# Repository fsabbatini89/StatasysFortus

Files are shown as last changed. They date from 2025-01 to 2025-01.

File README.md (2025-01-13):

# StatasysFortus
This is a man-in-the-middle technique for Statasys Fortus machine

Basically you put a real cartdrige on each bay with full filament on it.
The PCB of the bay is connected to this project board input and output is connected to the original
fortus cable.
This PCB captures the "WRITE ON CARTDRIGE" commands from the main cpu to the bay pcb and replies accordingly
but that message never gets to the bay pcb so the chip is never ever written so after a machine reset, cartdrige is
full again.

Cartridge cache file of machine as to be erased so the serial number of cartrige is forggoten at startup so machine thinks
new full filament is set.

Happy printing!

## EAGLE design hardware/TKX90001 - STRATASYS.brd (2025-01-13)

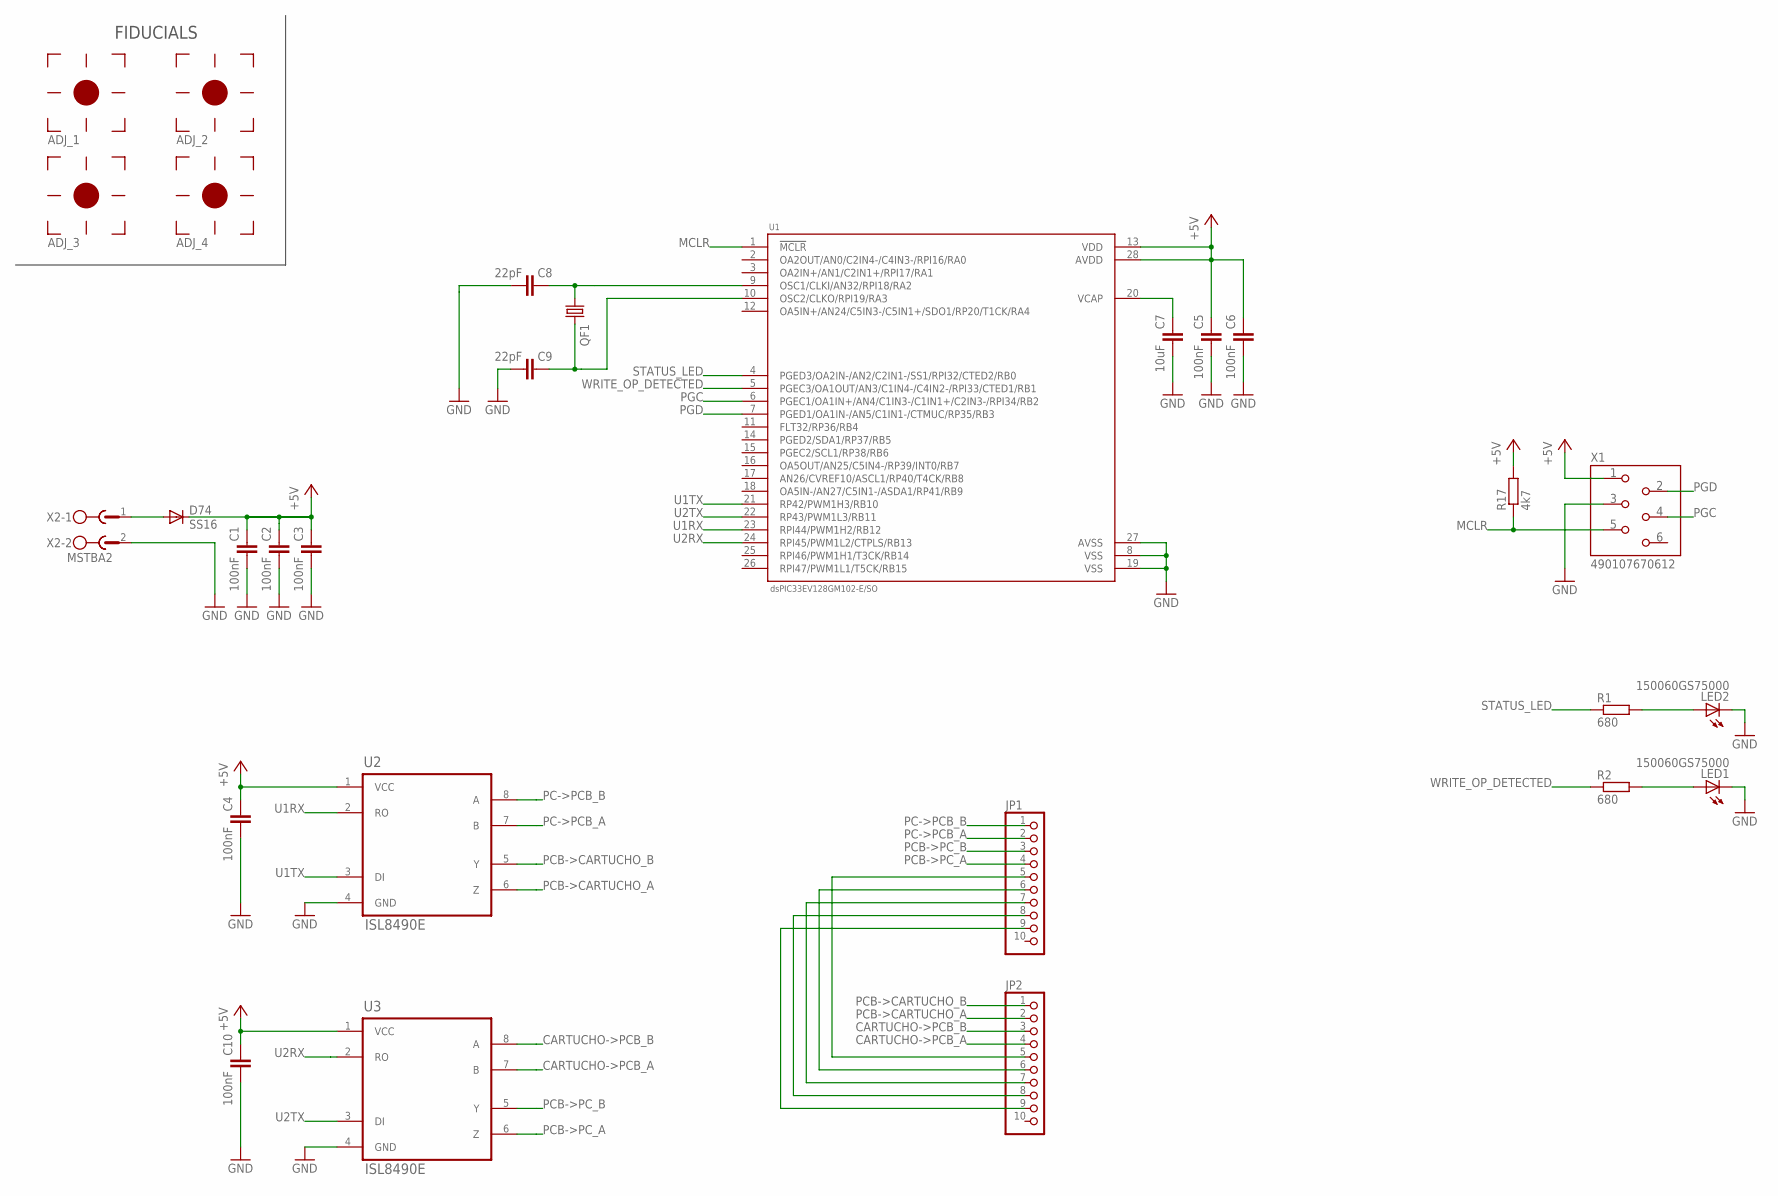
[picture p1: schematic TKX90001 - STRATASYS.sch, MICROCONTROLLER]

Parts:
ADJ_1, ADJ_2, ADJ_3, ADJ_4: FIDUCIAL
C1, C2, C3, C4, C5, C6, C10: 100nF; C0603K; PARTNO 885012206020
C7: 10uF; C1206K; PARTNO TAJA106K016RNJV
C8, C9: 22pF; C0603K; PARTNO C0603C220M4RACAUTO
D74: SS16; SMB; PARTNO SS16T3G
JP1, JP2: PINHD-1X10/90; 1X10/90
LED1, LED2: 150060GS75000; SML0603; PARTNO 150060GS75000
QF1: CRYSTALHC49S; HC49/S
R1, R2: 680; R0603; PARTNO RC0603FR-13680RL
R17: 4k7; R0603; PARTNO RC0603FR-074K7L
U1: dsPIC33EV128GM102-E/SO; SOIC127P1028X256-28N; PARTNO dsPIC33EV128GM102-E/SO
U2, U3: ISL8490E; SOIC127P600X175-8N; PARTNO ISL8490EIBZ
X1: 490107670612; REDFIT_6POS
X2: MSTBA2

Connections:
+5V: C1.1, C2.1, C3.1, C4.1, C5.1, C6.1, C10.1, D74.C, R17.2, U1.13 (VDD), U1.28 (AVDD), U2.1 (VCC), U3.1 (VCC), X1.P$1
CARTUCHO->PCB_A: JP2.4, U3.7 (B)
CARTUCHO->PCB_B: JP2.3, U3.8 (A)
GND: C1.2, C2.2, C3.2, C4.2, C5.2, C6.2, C7.2, C8.2, C9.2, C10.2, LED1.C, LED2.C, U1.8 (VSS), U1.19 (VSS), U1.27 (AVSS), U2.4 (GND), U3.4 (GND), X1.P$3, X2.2
MCLR: R17.1, U1.1 (!MCLR), X1.P$5
unnamed: LED1.A, R2.2
unnamed: D74.A, X2.1
unnamed: C7.1, U1.20 (VCAP)
unnamed: C8.1, QF1.1, U1.9 (OSC1/CLKI/AN32/RPI18/RA2)
unnamed: LED2.A, R1.2
unnamed: C9.1, QF1.2, U1.10 (OSC2/CLKO/RPI19/RA3)
unnamed: JP1.5, JP2.5
unnamed: JP1.6, JP2.6
unnamed: JP1.7, JP2.7
unnamed: JP1.8, JP2.8
unnamed: JP1.9, JP2.9
PC->PCB_A: JP1.2, U2.7 (B)
PC->PCB_B: JP1.1, U2.8 (A)
PCB->CARTUCHO_A: JP2.2, U2.6 (Z)
PCB->CARTUCHO_B: JP2.1, U2.5 (Y)
PCB->PC_A: JP1.4, U3.6 (Z)
PCB->PC_B: JP1.3, U3.5 (Y)
PGC: U1.6 (PGEC1/OA1IN+/AN4/C1IN3-/C1IN1+/C2IN3-/R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), X1.P$4
PGD: U1.7 (PGED1/OA1IN-/AN5/C1IN1-/CTMUC/RP35/RB3), X1.P$2
STATUS_LED: R1.1, U1.4 (PGED3/OA2IN-/AN2/C2IN1-/SS1/RPI32/CTED2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)
U1RX: U1.23 (RPI44/PWM1H2/RB12), U2.2 (RO)
U1TX: U1.21 (RP42/PWM1H3/RB10), U2.3 (DI)
U2RX: U1.24 (RPI45/PWM1L2/CTPLS/RB13), U3.2 (RO)
U2TX: U1.22 (RP43/PWM1L3/RB11), U3.3 (DI)
WRITE_OP_DETECTED: R2.1, U1.5 (PGEC3/OA1OUT/AN3/C1IN4-/C4IN2-/RPI33/CT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)

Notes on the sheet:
FIDUCIALS

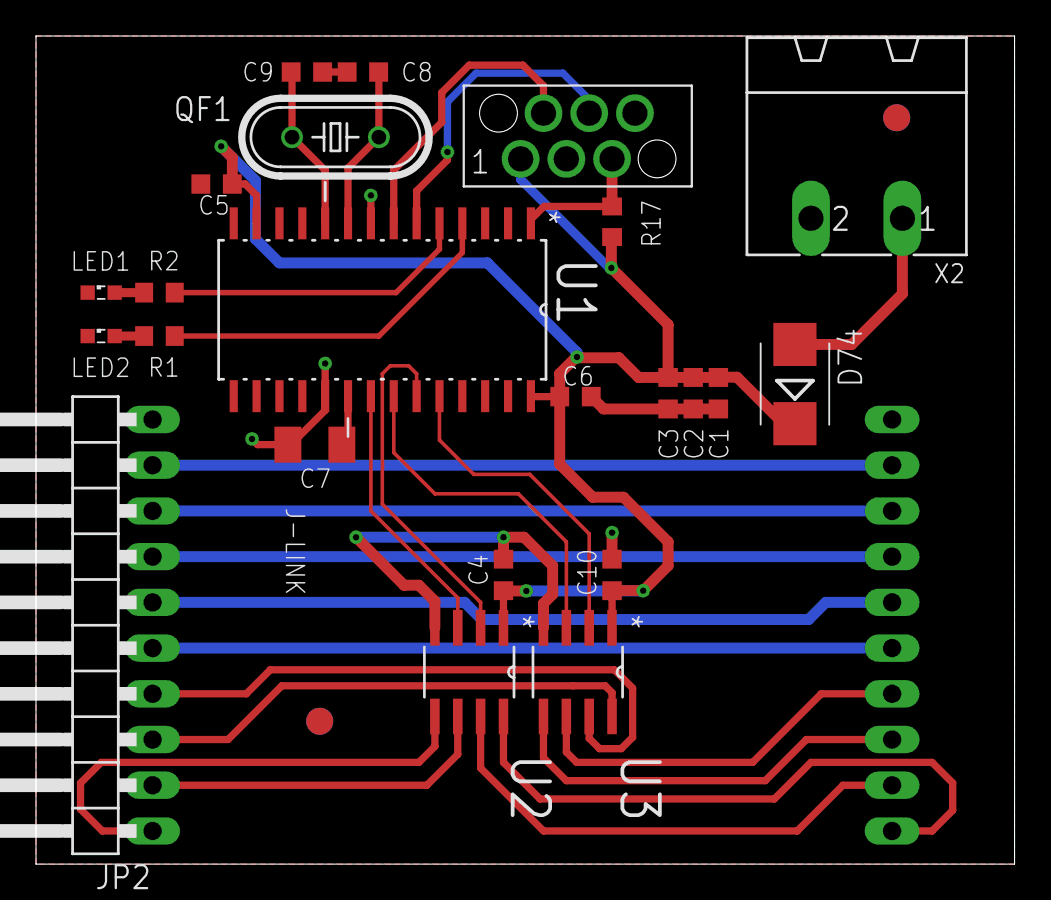
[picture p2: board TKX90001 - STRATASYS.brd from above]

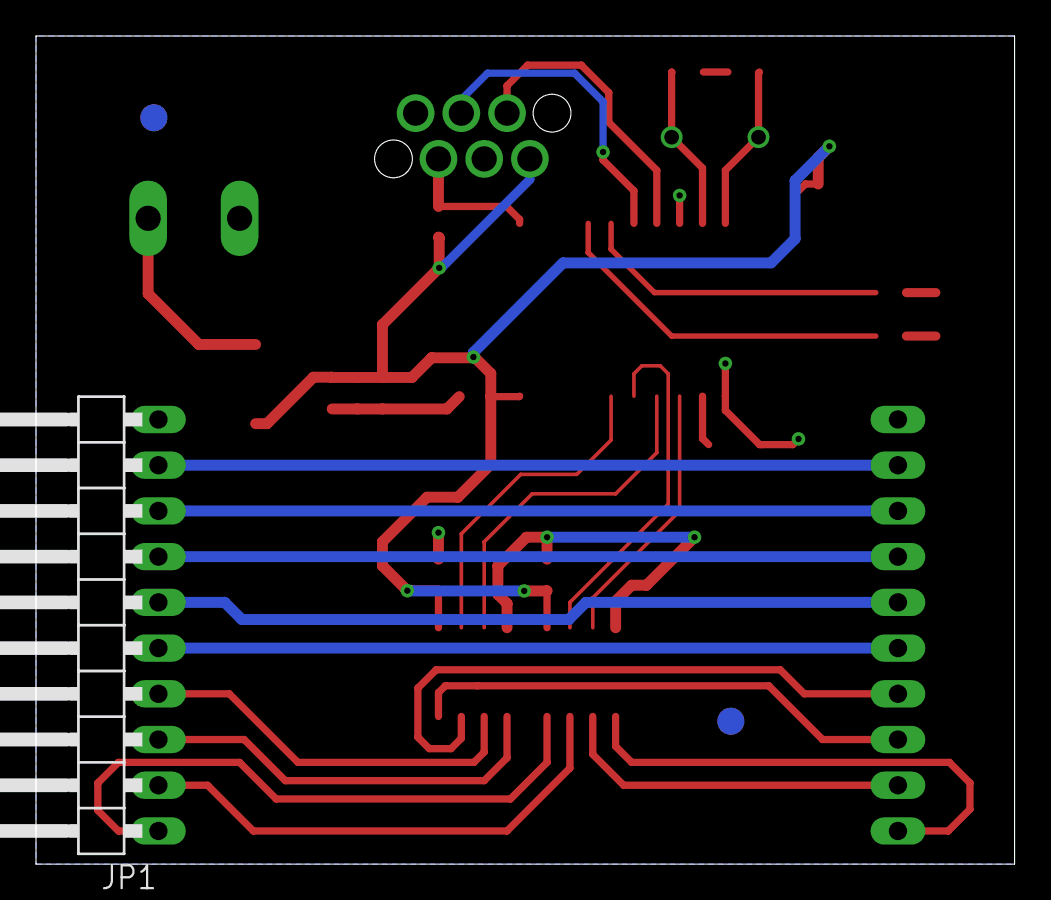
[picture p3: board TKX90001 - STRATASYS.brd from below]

Board: 2 copper layers, 54.4 x 46.0 mm, 28 parts (3 on the bottom side), 30 nets.

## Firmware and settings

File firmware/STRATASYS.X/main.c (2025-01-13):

/******************************************************************************/
/* Files to Include                                                           */
/******************************************************************************/

/* Device header file */
#if defined(__XC16__)
    #include <xc.h>
#elif defined(__C30__)
    #if defined(__dsPIC30F__)
        #include <p30Fxxxx.h>
    #endif
#endif

#include <stdint.h>        /* Includes uint16_t definition                    */
#include <stdbool.h>       /* Includes true/false definition                  */

#include "system.h"        /* System funct/params, like osc/peripheral config */
#include "user.h"          /* User funct/params, such as InitApp              */
#include "stratasys/pkt.h"

#include <uart.h>

/******************************************************************************/
/* Global Variable Declaration                                                */
/******************************************************************************/
RSTATE host; 
RSTATE cartdrige; 
RSTATE *r1 = &host;
RSTATE *r2 = &cartdrige;

/* HOST TO CARTDRIGE */
uint8_t pbuf[PKT_MAX_PLEN];
uint8_t dbuf[PKT_MAX_DLEN];

/* CARTRIDGE TO HOST */
uint8_t pbuf2[PKT_MAX_PLEN];
uint8_t dbuf2[PKT_MAX_DLEN];

uint8_t pkt_buf[PKT_MAX_PLEN];
uint8_t pkt_ibuf[PKT_MAX_PLEN];
uint8_t pkt_send_buf[PKT_MAX_PLEN + PKT_N_LEADIN];

uint8_t pkt_buf2[PKT_MAX_PLEN];
uint8_t pkt_ibuf2[PKT_MAX_PLEN];
uint8_t pkt_send_buf2[PKT_MAX_PLEN + PKT_N_LEADIN];

uint8_t cmdWriteData[PKT_MAX_DLEN];
uint16_t cmdWriteDataLength;

uint8_t ABS_M30_FULL[130] = {0x00 ,0x80 ,0x02 ,0x7f ,0x12 ,0xca ,0x6b ,0x41 ,0xe3 ,0xcd ,0x50 ,0xe9 ,0x80 ,0x84 ,0x37 ,0x53 ,0x22 ,0x8e ,0xe1 ,0x35 ,0x05 ,0x6f ,0x27 ,0xad ,0x58 ,0xf2 ,0x07 ,0x5f ,0xf3 ,0x9d ,0xbf ,0xdd ,0xf2 ,0x7f ,0x3c ,0x32 ,0xa1 ,0x6b ,0x55 ,0xbe ,0xed ,0x93 ,0x6d ,0x7d ,0x05 ,0x32 ,0xa5 ,0x79 ,0xe4 ,0xd8 ,0xa8 ,0x6d ,0x99 ,0xcb ,0xd1 ,0x09 ,0x97 ,0xe6 ,0xee ,0x4f ,0xac ,0xdc ,0xf3 ,0xdf ,0xcc ,0x84 ,0x41 ,0xe2 ,0x78 ,0x30 ,0x32 ,0x5a ,0xe9 ,0x89 ,0x61 ,0x75 ,0xe6 ,0xdc ,0x76 ,0xb6 ,0x89 ,0xf6 ,0xba ,0xc0 ,0x31 ,0xf3 ,0x18 ,0xd6 ,0x87 ,0x35 ,0x3b ,0x98 ,0x9a ,0xc8 ,0x38 ,0x25 ,0x60 ,0x44 ,0x54 ,0x0d ,0x3a ,0x2d ,0xd8 ,0x4d ,0x13 ,0x16 ,0x53 ,0x54 ,0x52 ,0x41 ,0x54 ,0x41 ,0x53 ,0x59 ,0x53 ,0x9b ,0xaa ,0xff ,0xf0 ,0x82 ,0x3f ,0xa0 ,0x38 ,0x11 ,0xad ,0x82 ,0x86 ,0xfd ,0xf9 ,0x89};

uint8_t lastCommandNumber;

bool waitForHost = true;

/******************************************************************************/
/* Main Program                                                               */
/******************************************************************************/

enum {
    WRITE_CATRIDGE_WRITE,               /* HOST -> CARTDRIGE */
    WRITE_CATRIDGE_ACK_WRITE,           /* CARTDRIGE -> HOST */
    WRITE_CATRIDGE_WRITE_DONE,          /* CARTDRIGE -> HOST */
    WRITE_CATRIDGE_WAIT_FOR_HOST_ASK,
    WRITE_CATRIDGE_ACK_WRITE_DONE,      /* HOST -> CARTDRIGE */
    WRITE_CATRIDGE_WAIT_FOR_HOST_READ,
    WRITE_CATRIDGE_READ_START          /* HOST -> CARTDRIGE */
};

uint8_t stateWrite;

volatile unsigned int pepe;

int16_t main(void)
{
    uint8_t *pdata1, pdata1_len;
    uint8_t *pdata2, pdata2_len;

    /* Configure the oscillator for the device */
    ConfigureOscillator();

    /* Initialize IO ports and peripherals */
    InitApp();

    stateWrite = WRITE_CATRIDGE_WRITE;
    
//    pbuf[0] = 'f';
//    pbuf[1] = 'r';
//    pbuf[2] = 'a';
//    pbuf[3] = 'n';
//    pbuf[4] = 'c';
//    pbuf[5] = 'o';
//
//    LATBbits.LATB1 = 0;
//    LATBbits.LATB1 = 1;
//            
//    while(1){
//        pkt_send2(r2, 1, 2, 3, PKTF_RESP_WRITE_CARTDRIGE, 6, pbuf);
//        LATBbits.LATB0 ^= 1;
//        LATBbits.LATB1 ^= 1;
//        delay_ms(1000);
//    }
    
    while(1)
    {
        switch(stateWrite){
            case WRITE_CATRIDGE_ACK_WRITE:
                /* To this command we need to answer with PKTF_RESP_WRITE_CARTDRIGE and 0 data */                
                pdata2 = NULL;
                pdata2_len = 0;
                pkt_send(r2, PKT_SRC(pbuf), PKT_DST(pbuf), PKT_NUMCMD(pbuf), PKTF_RESP_WRITE_CARTDRIGE, pdata2_len, pdata2);
                
                stateWrite = WRITE_CATRIDGE_WRITE_DONE;
            break;
                           
            case WRITE_CATRIDGE_WRITE_DONE:
                /* To this command we need to answer with PKTF_RESP_WRITTEN_CARTDRIGE and 0 data */                
                pdata2 = NULL;
                pdata2_len = 0;
                    
                lastCommandNumber++;
                    
                pkt_send(r2, PKT_SRC(pbuf), PKT_DST(pbuf), lastCommandNumber, PKTF_RESP_WRITTEN_CARTDRIGE, pdata2_len, pdata2);
                
                stateWrite = WRITE_CATRIDGE_WAIT_FOR_HOST_ASK;
                
            break;
                
            case WRITE_CATRIDGE_ACK_WRITE_DONE:    
                /* To this command we need to answer with PKTF_RESP_WRITE_CARTDRIGE and 0 data */                
                pdata2 = NULL;
                pdata2_len = 0;

                pkt_send(r2, PKT_SRC(pbuf), PKT_DST(pbuf), PKT_NUMCMD(pbuf), PKTF_RESP_ASK_WRITE_DONE_CARTDRIGE, pdata2_len, pdata2);
                    
                stateWrite = WRITE_CATRIDGE_READ_START;
            break;
                
            case WRITE_CATRIDGE_READ_START:                            
                /* To this command we need to answer with PKTF_RESP_WRITE_CARTDRIGE and 0 data */                
                pdata2 = cmdWriteData;
                pdata2_len = cmdWriteDataLength;

                lastCommandNumber++;
                
                //Respond as cartridge is useful
//                if(pdata2_len == 3){
//                    uint8_t* p = pdata2;
//                    if((*(++p) == 0x81) && (*(++p) == 0x55)){
//                        *p = 0x00;
//                    }
//                }
                
                pkt_send(r2, PKT_SRC(pbuf), PKT_DST(pbuf), PKT_NUMCMD(pbuf), PKTF_RESP_READ_CARTDRIGE, pdata2_len, pdata2);

                stateWrite = WRITE_CATRIDGE_WRITE;
                    
            break;
        }
                
        /* Host instruction received */
        if(r1->rx){   
            int8_t err;
                    
            /*
            * received an RS485 packet, copy it to our local buffer and
            * reset the rx flag so that new packets can be received.
            */
            DisableIntU1RX;
            memcpy(pbuf, r1->rbuf, PKT_LEN(r1->rbuf));
            err = r1->err;
            r1->rx = 0;
            IFS0bits.U1RXIF = 0;
            EnableIntU1RX;

            pdata1 = NULL;
            pdata1_len = 0;
            
            uint8_t cmd = PKT_COMMAND(pbuf);
            
            if(cmd == PKTF_CMD_ACK){
                /* Save last command number for future use */
                lastCommandNumber = PKT_NUMCMD(pbuf);
            }
        
            if(cmd == PKTF_CMD_WRITE_CARTDRIGE){
                /* Save data as we need to respond with it later on */
                cmdWriteDataLength = PKT_DLEN(pbuf);
                memcpy(cmdWriteData, PKT_DATA(pbuf), cmdWriteDataLength);
                
                //LATBbits.LATB1 ^= 1;
                
                stateWrite = WRITE_CATRIDGE_ACK_WRITE;
            }   
            
            if((cmd == PKTF_CMD_ASK_WRITE_DONE_CARTDRIGE) && (stateWrite == WRITE_CATRIDGE_WAIT_FOR_HOST_ASK)){  
                stateWrite = WRITE_CATRIDGE_ACK_WRITE_DONE;
            }              
            
            if((cmd == PKTF_CMD_ACK) && (stateWrite == WRITE_CATRIDGE_WAIT_FOR_HOST_READ)){                
                stateWrite = WRITE_CATRIDGE_READ_START;
            }

            /* Forward all messages from host to cartridge */
            if(stateWrite == WRITE_CATRIDGE_WRITE){
                pkt_send(r1, PKT_DST(pbuf), PKT_SRC(pbuf), PKT_NUMCMD(pbuf), PKT_COMMAND(pbuf), PKT_DLEN(pbuf), PKT_DATA(pbuf));
                
                waitForHost = false;
            }     
        }
        
        
        
        
        
        /* Cartridge instruction received */
        if(r2->rx){   
            int8_t err2;
            uint16_t len;
                    
            /*
            * received an RS485 packet, copy it to our local buffer and
            * reset the rx flag so that new packets can be received.
            */
            
            DisableIntU2RX;
            memcpy(pbuf2, r2->rbuf, PKT_MAX_PLEN);
            len = PKT_LEN(r2->rbuf);
            
            err2 = r2->err;
            r2->rx = 0;
            IFS1bits.U2RXIF = 0;
            EnableIntU2RX;

            pdata2 = NULL;
            pdata2_len = 0;
            
            uint8_t cmd = PKT_COMMAND(pbuf2);
            
            //Respond as cartridge is useful
            if((cmd == PKTF_RESP_READ_CARTDRIGE) && (PKT_DLEN(pbuf2) == 3)){
                uint8_t* p = PKT_DATA(pbuf2);
                if((*(++p) == 0x81) && (*(++p) == 0x55)){
                    *p = 0x00;
                }
            }
            
//            if((cmd == PKTF_RESP_READ_CARTDRIGE) && (PKT_DLEN(pbuf2) == 0x82)){
//                uint8_t* p = PKT_DATA(pbuf2);
//                memcpy(p, ABS_M30_FULL, 130);
//            }
            
            /* Forward all messages from cartridge to host */
            if(stateWrite == WRITE_CATRIDGE_WRITE){                            
                pkt_send2(r2, PKT_DST(pbuf2), PKT_SRC(pbuf2), PKT_NUMCMD(pbuf2), PKT_COMMAND(pbuf2), PKT_DLEN(pbuf2), PKT_DATA(pbuf2));
            }
        }
    }
}

/* This is UART1 transmit ISR */
void __attribute__((interrupt, no_auto_psv)) _U1TXInterrupt(void)
{
    IFS0bits.U1TXIF = 0;
    
    if(i1r){
        U1TXREG = i1r->sbuf[i1r->sidx++]; //Transfer next byte of message
             
        if(i1r->sidx == i1r->slen) {    //Message transfer complete
            i1r->tx_complete = 1;
            //PIE1bits.TXIE = 0; //EUSART transmit interrupt disable
            DisableIntU1TX;
            return;
        }
    }
}

void __attribute__((interrupt, no_auto_psv)) _U1ErrInterrupt(void)
{
    unsigned int rchar;
    
    if(U1STAbits.OERR || U1STAbits.FERR || U1STAbits.PERR ){
        U1STAbits.OERR = 0;
        U1STAbits.FERR = 0;
        U1STAbits.PERR = 0;
        rchar = U1RXREG;
        pkt_abort(i1r);
        return;
    }
}

/* This is UART1 receive ISR */
void __attribute__((interrupt, no_auto_psv)) _U1RXInterrupt(void)
{
    unsigned int rchar;
    IFS0bits.U1RXIF = 0;
    
    if(U1STAbits.OERR || U1STAbits.FERR || U1STAbits.PERR ){
        U1STAbits.OERR = 0;
        U1STAbits.FERR = 0;
        U1STAbits.PERR = 0;
        rchar = U1RXREG;
        pkt_abort(i1r);
        return;
    }
   
    if(i1r){
        while(DataRdyUART1()){
            pkt_byte_rx(i1r, ReadUART1());
            //LATBbits.LATB0 ^= 1;
        }
    }
    
//    IEC0bits.U1RXIE = 1;
} 

/* This is UART2 transmit ISR */
void __attribute__((interrupt, no_auto_psv)) _U2TXInterrupt(void)
{
    IFS1bits.U2TXIF = 0;
        
    if(i2r){
        U2TXREG = i2r->sbuf[i2r->sidx++]; //Transfer next byte of message
             
        if(i2r->sidx == i2r->slen) {    //Message transfer complete
            i2r->tx_complete = 1;
            DisableIntU2TX;
            return;
        }
    }
}

void __attribute__((interrupt, no_auto_psv)) _U2ErrInterrupt(void)
{
    unsigned int rchar;
    
    if(U2STAbits.OERR || U2STAbits.FERR || U2STAbits.PERR ){
        U2STAbits.OERR = 0;
        U2STAbits.FERR = 0;
        U2STAbits.PERR = 0;
        rchar = U2RXREG;
        pkt_abort(i2r);
        return;
    }
}

/* This is UART2 receive ISR */
void __attribute__((interrupt, no_auto_psv)) _U2RXInterrupt(void)
{
    unsigned int rchar;
    IFS1bits.U2RXIF = 0;
    
    if(U2STAbits.OERR || U2STAbits.FERR || U2STAbits.PERR ){
        U2STAbits.OERR = 0;
        U2STAbits.FERR = 0;
        U2STAbits.PERR = 0;
        rchar = U2RXREG;
        pkt_abort(i2r);
        return;
    }
    
    if(i2r){
        while(DataRdyUART2()){
            rchar = ReadUART2();
           // if(waitForHost == false){
                pkt_byte_rx2(i2r, rchar);
           // }
            //LATBbits.LATB0 ^= 1;
        }
    }
} 

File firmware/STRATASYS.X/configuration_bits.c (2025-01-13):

/******************************************************************************/
/* Files to Include                                                           */
/******************************************************************************/

/******************************************************************************/
/* Configuration Bits                                                         */
/*                                                                            */
/* This is not all available configuration bits for all dsPIC devices.        */
/* Refer to the dsPIC device specific .h file in the compiler installation    */
/* support\dsPIC30F\h directory for complete options specific to the device   */
/* selected.  For additional information about what the hardware              */
/* configurations mean in terms of device operation, refer to the device      */
/* datasheet 'Special Features' chapter.                                      */
/*                                                                            */
/* A feature of MPLAB X is the 'Generate Source Code to Output' utility in    */
/* the Configuration Bits window.  Under Window > PIC Memory Views >          */
/* Configuration Bits, a user controllable configuration bits window is       */
/* available to generate configuration bits source code which the user can    */
/* then paste into this project.                                              */
/******************************************************************************/

// FSEC
#pragma config BWRP = OFF               // Boot Segment Write-Protect Bit (Boot Segment may be written)
#pragma config BSS = DISABLED           // Boot Segment Code-Protect Level bits (No Protection (other than BWRP))
#pragma config BSS2 = OFF               // Boot Segment Control Bit (No Boot Segment)
#pragma config GWRP = OFF               // General Segment Write-Protect Bit (General Segment may be written)
#pragma config GSS = DISABLED           // General Segment Code-Protect Level bits (No Protection (other than GWRP))
#pragma config CWRP = OFF               // Configuration Segment Write-Protect Bit (Configuration Segment may be written)
#pragma config CSS = DISABLED           // Configuration Segment Code-Protect Level bits (No Protection (other than CWRP))
#pragma config AIVTDIS = DISABLE        // Alternate Interrupt Vector Table Disable Bit  (Disable Alternate Vector Table)

// FBSLIM
#pragma config BSLIM = 0x1FFF           // Boot Segment Code Flash Page Address Limit Bits (Boot Segment Flash Page Address Limit (0-0x1FFF))

// FOSCSEL
#pragma config FNOSC = PRIPLL              // Initial oscillator Source Selection Bits (Primary oscillator w/PLL)
#pragma config IESO = OFF               // Two Speed Oscillator Start-Up Bit (Start up device with user selected oscillator source)

// FOSC
#pragma config POSCMD = HS              // Primary Oscillator Mode Select Bits (Primary Oscillator Crystal)
#pragma config OSCIOFNC = OFF           // OSC2 Pin I/O Function Enable Bit (OSC2 is clock output)
#pragma config IOL1WAY = OFF             // Peripheral Pin Select Configuration Bit (Allow Only One reconfiguration)
#pragma config FCKSM = CSDCMD           // Clock Switching Mode Bits (Both Clock Switching and Fail-safe Clock Monitor are disabled)
#pragma config PLLKEN = ON              // PLL Lock Enable Bit (Clock switch to PLL source will wait until the PLL lock signal is valid)

// FWDT
#pragma config WDTPOST = PS32768        // Watchdog Timer Postscaler Bits (1:32,768)
#pragma config WDTPRE = PR128           // Watchdog Timer Prescaler Bit (1:128)
#pragma config FWDTEN = OFF             // Watchdog Timer Enable Bits (WDT Enabled)
#pragma config WINDIS = OFF             // Watchdog Timer Window Enable Bit (Watchdog timer in Non-Window Mode)
#pragma config WDTWIN = WIN25           // Watchdog Window Select Bits (WDT Window is 25% of WDT period)

// FPOR
#pragma config BOREN0 = ON              // Brown Out Reset Detection Bit (BOR is Enabled)

// FICD
#pragma config ICS = PGD1               // ICD Communication Channel Select Bits (Communicate on PGEC1 and PGED1)

// FDMTINTVL
#pragma config DMTIVTL = 0xFFFF         // Lower 16 Bits of 32 Bit DMT Window Interval (Lower 16 bits of 32 bit DMT window interval (0-0xFFFF))

// FDMTINTVH
#pragma config DMTIVTH = 0xFFFF         // Upper 16 Bits of 32 Bit DMT Window Interval (Upper 16 bits of 32 bit DMT window interval (0-0xFFFF))

// FDMTCNTL
#pragma config DMTCNTL = 0xFFFF         // Lower 16 Bits of 32 Bit DMT Instruction Count Time-Out Value (Lower 16 bits of 32 bit DMT instruction count time-out value (0-0xFFFF))

// FDMTCNTH
#pragma config DMTCNTH = 0xFFFF         // Upper 16 Bits of 32 Bit DMT Instruction Count Time-Out Value (Upper 16 bits of 32 bit DMT instruction count time-out value (0-0xFFFF))

// FDMT
#pragma config DMTEN = DISABLE           // Dead Man Timer Disable Bit (Dead Man Timer is Enabled and cannot be enabled by software)

// FDEVOPT
#pragma config PWMLOCK = ON             // PWM Lock Enable Bit (Certain PWM registers may only be written after key sequence)
#pragma config ALTI2C1 = OFF            // Alternate I2C1 Pins Selection Bit (I2C1 mapped to SDA1/SCL1 pins)

// FALTREG
#pragma config CTXT1 = NONE             // Interrupt Priority Level (IPL) Selection Bits For Alternate Working Register Set 1 (Not Assigned)
#pragma config CTXT2 = NONE             // Interrupt Priority Level (IPL) Selection Bits For Alternate Working Register Set 2 (Not Assigned)

// #pragma config statements should precede project file includes.
// Use project enums instead of #define for ON and OFF.

/* Device header file */
#if defined(__XC16__)
    #include <xc.h>
#elif defined(__C30__)
    #if defined(__dsPIC30F__)
        #include <p30Fxxxx.h>
    #endif
#endif
